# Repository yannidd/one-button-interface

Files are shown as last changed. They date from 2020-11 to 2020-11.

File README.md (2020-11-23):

# One Button Interface

PCB layout and schematic and Arduino code for a single push-button interface that can be used to turn a device on/off as well as a user input to interact with the firmware on a microcontroller.

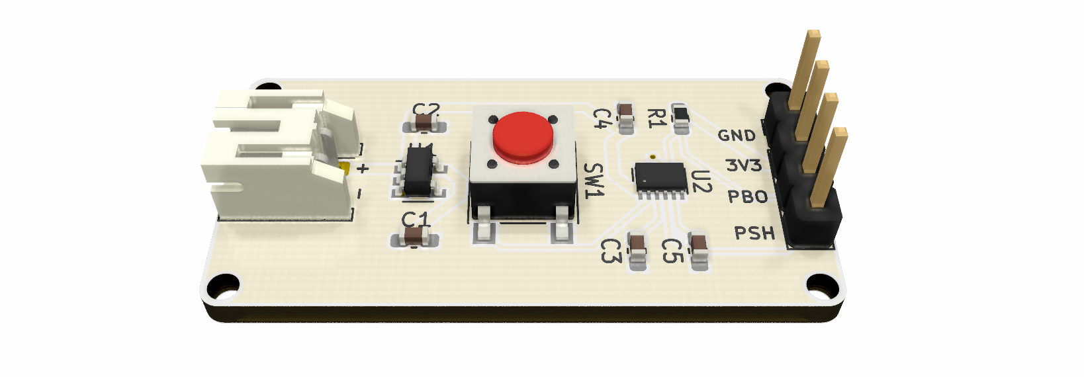
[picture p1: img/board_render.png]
Board render.


## BOM

Reference   | Quantity| Value                                                                       | RS Stock No.| Vendor
|-          |-        |-                                                                            |-            |-
C1 C2 C3 C5 |4        |1uF                                                                          |461-2708     |RS
C4          |1        |0.1uF                                                                        |264-4630     |RS
H1 H2 H3 H4 |4        |MountingHole                                                                 |~
J1          |1        |[Conn_01x02](https://docs.rs-online.com/cb9d/0900766b81347511.pdf)           |820-1494     |RS
J6          |1        |[Conn_01x04](https://docs.rs-online.com/cd6a/0900766b813c4c2e.pdf)           |360-6314     |RS
R1          |1        |10K                                                                          |182-9211     |RS
SW1         |1        |[PTS645SL50SMTR 92 LFS](https://docs.rs-online.com/62d0/0900766b815a8e9b.pdf)|135-9400     |RS
U1          |1        |[LD39015M33R](http://www.st.com/resource/en/datasheet/ld39015.pdf)           |795-8965     |RS
U2          |1        |[STM6600](http://www.st.com/resource/en/datasheet/stm6600.pdf)               |189-2069     |RS

## Directory Tree

- arduino - Arduino source code with an example application.
- img - Supplementary images
- pcb - PCB schematic, layout and BOM.
  - kicad - Design files for KiCad EDA.

## Connection Diagram

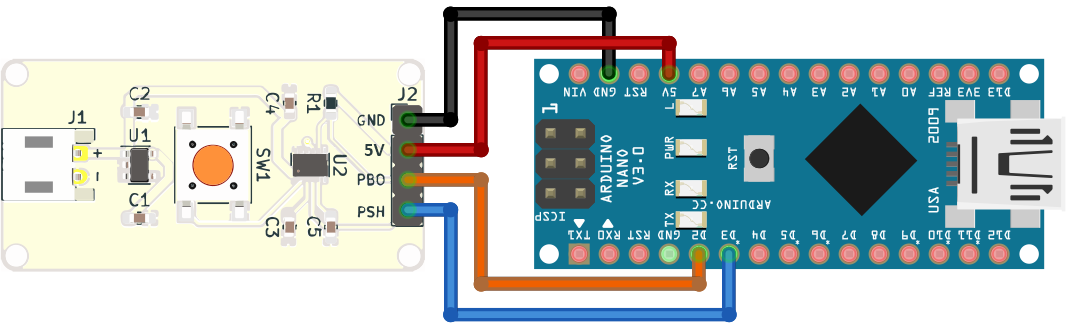
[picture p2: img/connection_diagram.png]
Connection Diagram


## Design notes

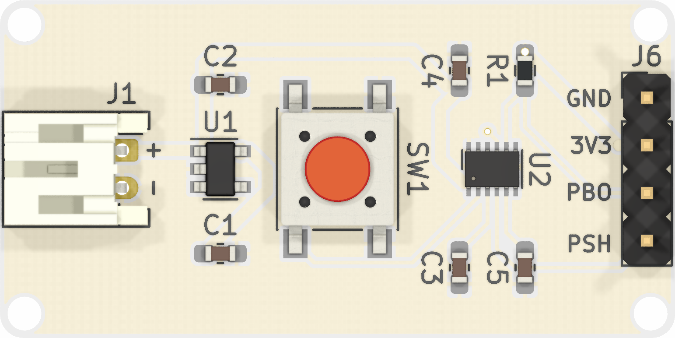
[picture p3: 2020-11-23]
img/board_render_top.png

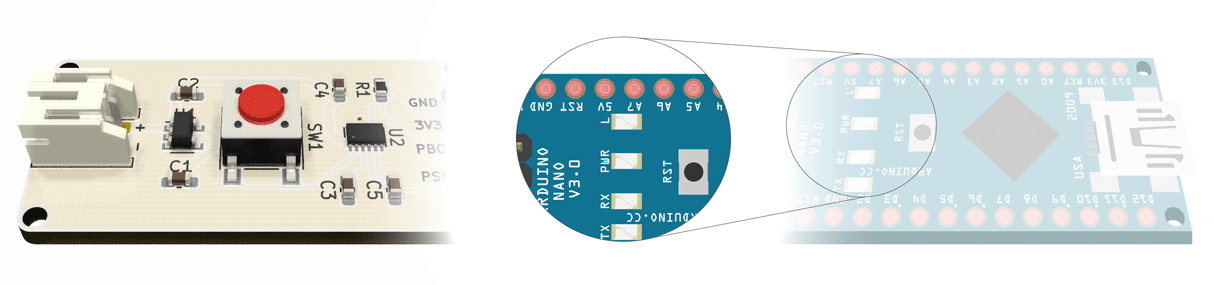
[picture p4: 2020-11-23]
img/animation.gif

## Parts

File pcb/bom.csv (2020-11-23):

Reference | Quantity | Value | Footprint | Datasheet | RS Stock No. | Vendor
C1 C2 C3 C5 | 4 | 1uF | Capacitor_SMD:C_0603_1608Metric_Pad1.08x0.95mm_HandSolder | ~ | 461-2708 | RS
C4 | 1 | 0.1uF | Capacitor_SMD:C_0603_1608Metric_Pad1.08x0.95mm_HandSolder | ~ | 264-4630 | RS
H1 H2 H3 H4 | 4 | MountingHole | one_button_interface:MountingHole_M1.6 | ~
J1 | 1 | Conn_01x02 | Connector_JST:JST_PH_S2B-PH-K_1x02_P2.00mm_Horizontal | https://docs.rs-online.com/cb9d/0900766b81347511.pdf | 820-1494 | RS
J6 | 1 | Conn_01x04 | Connector_PinHeader_2.54mm:PinHeader_1x04_P2.54mm_Vertical | https://docs.rs-online.com/cd6a/0900766b813c4c2e.pdf | 360-6314 | RS
R1 | 1 | 10K | Resistor_SMD:R_0603_1608Metric_Pad0.98x0.95mm_HandSolder | ~ | 182-9211 | RS
SW1 | 1 | PTS645SL50SMTR 92 LFS | Button_Switch_SMD:SW_SPST_PTS645 | https://docs.rs-online.com/62d0/0900766b815a8e9b.pdf | 135-9400 | RS
U1 | 1 | LD39015M33R | Package_TO_SOT_SMD:SOT-23-5 | http://www.st.com/resource/en/datasheet/ld39015.pdf | 795-8965 | RS
U2 | 1 | STM6600 | Package_DFN_QFN:TDFN-12_2x3mm_P0.5mm | http://www.st.com/resource/en/datasheet/stm6600.pdf | 189-2069 | RS

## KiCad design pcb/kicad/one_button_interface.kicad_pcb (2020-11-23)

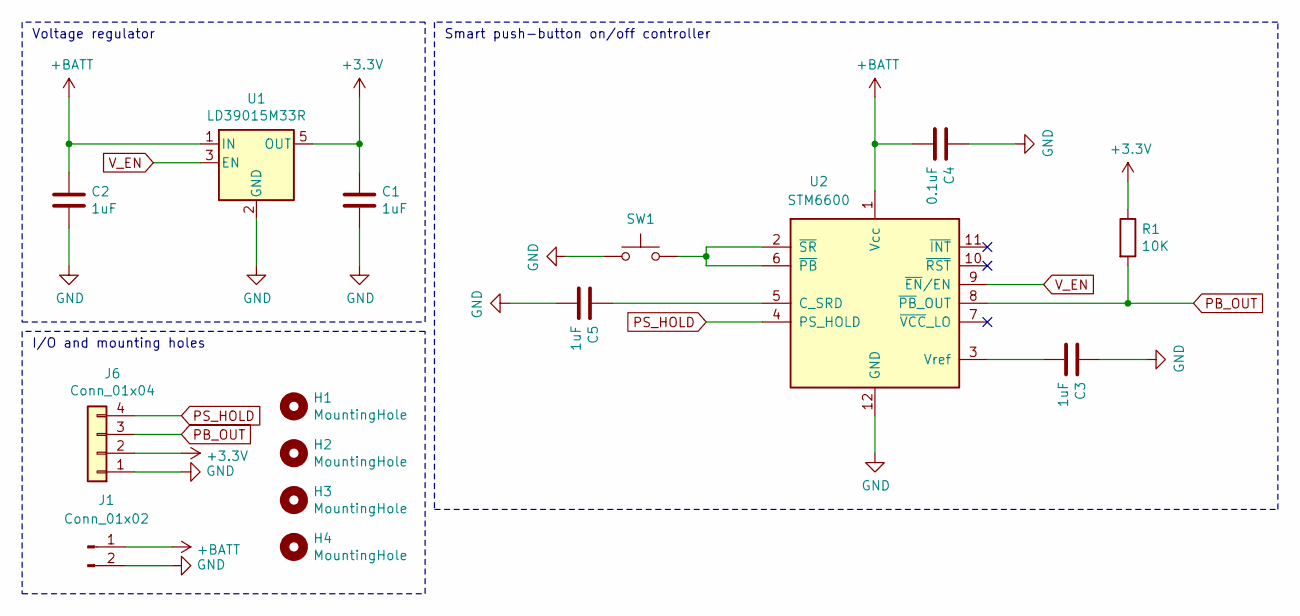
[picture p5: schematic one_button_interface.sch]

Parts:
C1, C2, C3, C5: 1uF; C_0603_1608Metric_Pad1.08x0.95mm_HandSolder
C4: 0.1uF; C_0603_1608Metric_Pad1.08x0.95mm_HandSolder
H1, H2, H3, H4: MountingHole; MountingHole_M1.6
J1: Conn_01x02; JST_PH_S2B-PH-K_1x02_P2.00mm_Horizontal
J6: Conn_01x04; PinHeader_1x04_P2.54mm_Vertical
R1: 10K; R_0603_1608Metric_Pad0.98x0.95mm_HandSolder
SW1: PTS645SL50SMTR 92 LFS; SW_SPST_PTS645
U1: LD39015M33R; SOT-23-5
U2: STM6600; TDFN-12_2x3mm_P0.5mm

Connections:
+3V3: C1.1, J6.2, R1.1, U1.5 (OUT)
+BATT: C2.1, C4.2, J1.1, U1.1 (IN), U2.1 (Vcc)
GND: C1.2, C2.2, C3.1, C4.1, C5.2, J1.2, J6.1, SW1.1, U1.2 (GND), U2.12 (GND)
unnamed: C3.2, U2.3 (Vref)
unnamed: C5.1, U2.5 (C_SRD)
unnamed: SW1.2, U2.2 (~SR~), U2.6 (~PB~)
PB_OUT: J6.3, R1.2, U2.8 (~PB~_OUT)
PS_HOLD: J6.4, U2.4 (PS_HOLD)
V_EN: U1.3 (EN), U2.9 (~EN~/EN)

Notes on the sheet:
Voltage regulator
Smart push-button on/off controller
I/O and mounting holes

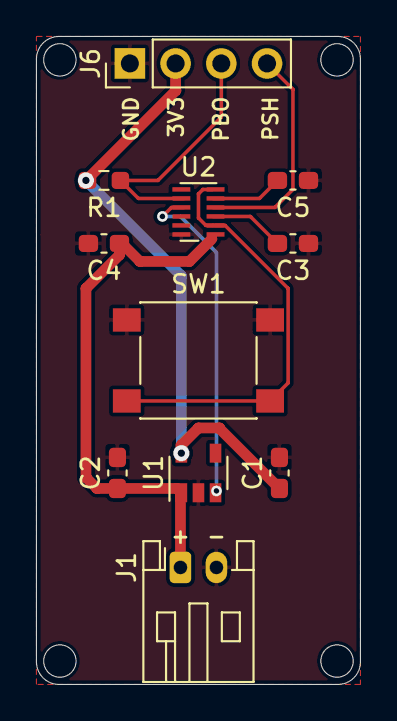
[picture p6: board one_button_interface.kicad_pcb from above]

Board: 4 copper layers, 18.0 x 36.0 mm, 15 parts (0 on the bottom side), 9 nets.

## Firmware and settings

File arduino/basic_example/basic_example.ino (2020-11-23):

#include <AceButton.h>

using namespace ace_button;

const int LED_PIN = LED_BUILTIN;
const int PB_OUT_PIN = 2;
const int PS_HOLD_PIN = 3;

AceButton button(PB_OUT_PIN);

void buttonEventHandler(AceButton*, uint8_t, uint8_t);

void setup() {
  // Initialise I/O.  
  pinMode(LED_PIN, OUTPUT);
  pinMode(PB_OUT_PIN, INPUT_PULLUP);
  pinMode(PS_HOLD_PIN, OUTPUT);

  // Set the power supply pin high to keep the device on.
  digitalWrite(PS_HOLD_PIN, HIGH);

  // Initialise serial communication. 
  Serial.begin(9600);
  Serial.println("Click: power on.");

  // Setup button functionality.
  ButtonConfig* buttonConfig = button.getButtonConfig();
  buttonConfig->setEventHandler(buttonEventHandler);
  buttonConfig->setFeature(ButtonConfig::kFeatureDoubleClick);
  buttonConfig->setFeature(ButtonConfig::kFeatureSuppressAll);  
  buttonConfig->setFeature(ButtonConfig::kFeatureLongPress);
}

void loop() {
  // Should be called every 20ms or faster for the default debouncing time of ~50ms.
  button.check();
  delay(10);
}

void buttonClicked() {
  Serial.println("Click: LED on.");
  digitalWrite(LED_PIN, HIGH);
}

void buttonDoubleClicked() {
  Serial.println("Double click: LED off.");
  digitalWrite(LED_PIN, LOW);
}

void buttonLongPressed() {
  Serial.println("Long press: power off.");
  // Set the power supply pin low to shut the device down.
  digitalWrite(PS_HOLD_PIN, HIGH);
}

// The event handler for the button.
void buttonEventHandler(AceButton* button, uint8_t eventType, uint8_t buttonState) {
  switch (eventType) {    
    case AceButton::kEventLongPressed:      
      buttonLongPressed();
      break;
    case AceButton::kEventDoubleClicked: 
      buttonDoubleClicked();
      break;    
    case AceButton::kEventClicked:
    case AceButton::kEventReleased:
      buttonClicked();
      break;
  }
}
